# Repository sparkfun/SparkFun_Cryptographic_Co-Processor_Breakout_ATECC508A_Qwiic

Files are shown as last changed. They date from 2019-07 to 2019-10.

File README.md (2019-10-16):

SparkFun Cryptographic Co-Processor Breakout - ATECC508A (Qwiic)
========================================

SparkFun Cryptographic Breakout

[*SparkFun Cryptographic Co-Processor Breakout - ATECC508A (Qwiic) (DEV-15573)*](https://www.sparkfun.com/products/15573)

The SparkFun Cryptographic Co-processor Breakout ATECC508A (Qwiic) takes all the great features of the Microchip ATECC508A cryptographic authentication device and adds two Qwiic ports for plug and play functionality. The ATECC508A chip is capable of many cryptographic processes, including, but not limited to:

* An asymmetric key/signature solution based upon Elliptic Curve Cryptography.
* A standard hash-based challenge-response protocol using a SHA-256 algorithm.
* A FIPS random number generator. 

Embedded in the chip is a 10 Kb EEPROM array that can be used for storing keys, certificates, data, consumption logging, and security configurations. Access to the sections of memory can then be restricted and the configuration locked to prevent changes.

Each ATECC508A ships with a guaranteed unique 72-bit serial number and includes several security features to prevent physical attacks on the device itself, or logical attacks on the data transmitted between the device.

**&#x1F512; Note:** This board is **NOT** capable of encrypting and decrypting data. It can however, perform quite a few cryptographic authentication processes such as secure private key creation, secure key storage, and digital signature creation and verification.

Repository Contents
-------------------

* **/Documentation** - Data sheets, additional product information
* **/Enclosure** - Enclosure files 
* **/Firmware** - Example code 
* **/Hardware** - Eagle design files (.brd, .sch)
* **/Libraries** - Libraries for use with the <PRODUCT NAME>
* **/Production** - Production panel files (.brd)
* **/Software** - Related software for the <PRODUCT NAME>

Documentation
--------------
* **[SparkFun ATECCX08A Arduino Library](https://github.com/sparkfun/SparkFun_ATECCX08a_Arduino_Library)** - Arduino library for the ATECCX08A.
* **[SparkFun Cryptographic Breakout Hookup Guide](https://learn.sparkfun.com/tutorials/cryptographic-co-processor-atecc508a-qwiic-hookup-guide)** - Basic hookup guide for the SparkFun Cryptographic Co-Processor Breakout.

Product Versions
----------------
* [DEV-15573](https://www.sparkfun.com/products/15573)- Initial Release

License Information
-------------------

This product is _**open source**_! 

Please review the LICENSE.md file for license information. 

If you have any questions or concerns on licensing, please contact technical support through the [SparkFun forum](https://forum.sparkfun.com/index.php).

Please use, reuse, and modify these files as you see fit. Please maintain attribution to SparkFun Electronics and release any derivative under the same license.

Distributed as-is; no warranty is given.

- Your friends at SparkFun.

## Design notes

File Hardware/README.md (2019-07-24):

SparkFun <PRODUCT NAME> Design Files
=====================================

The .sch and .brd files hare are Eagle CAD schematic and PCB design files from SparkFun Electronics.
A freeware version of Eagle can be found [here](http://www.cadsoftusa.com/download-eagle/freeware/).

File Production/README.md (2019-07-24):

SparkFun <PRODUCT NAME> Production Files
=========================================

These are the production files SparkFun uses for printing PCBs.

License Information
-------------------
This product is open source! 

The hardware is released under [Creative Commons ShareAlike 4.0 International](https://creativecommons.org/licenses/by-sa/4.0/).

Please use, reuse, and modify these files as you see fit. Please maintain attribution to SparkFun Electronics and release anything derivative under the same license.

Distributed as-is; no warranty is given.

- Your friends at SparkFun.

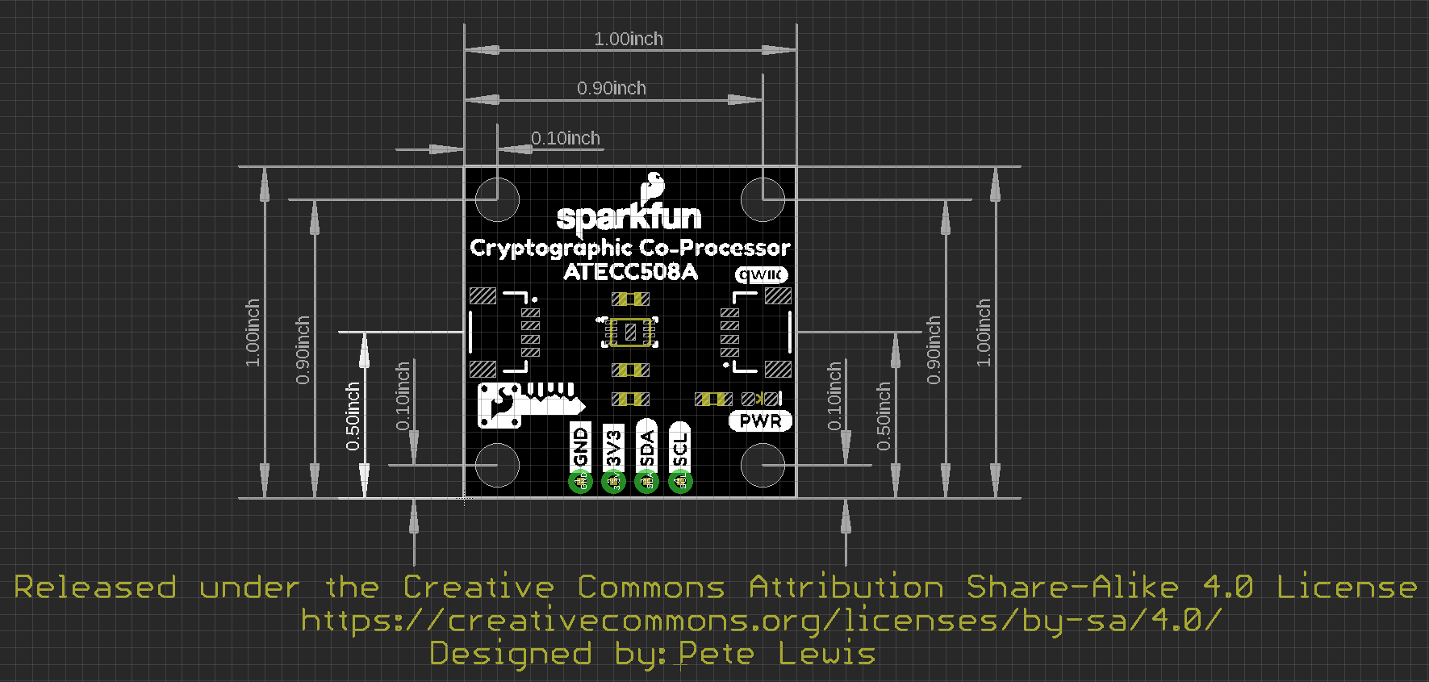
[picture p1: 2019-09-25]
Documentation/SparkFun_Cryptographic_Co-processor_ATECC508A_Dimensions.png

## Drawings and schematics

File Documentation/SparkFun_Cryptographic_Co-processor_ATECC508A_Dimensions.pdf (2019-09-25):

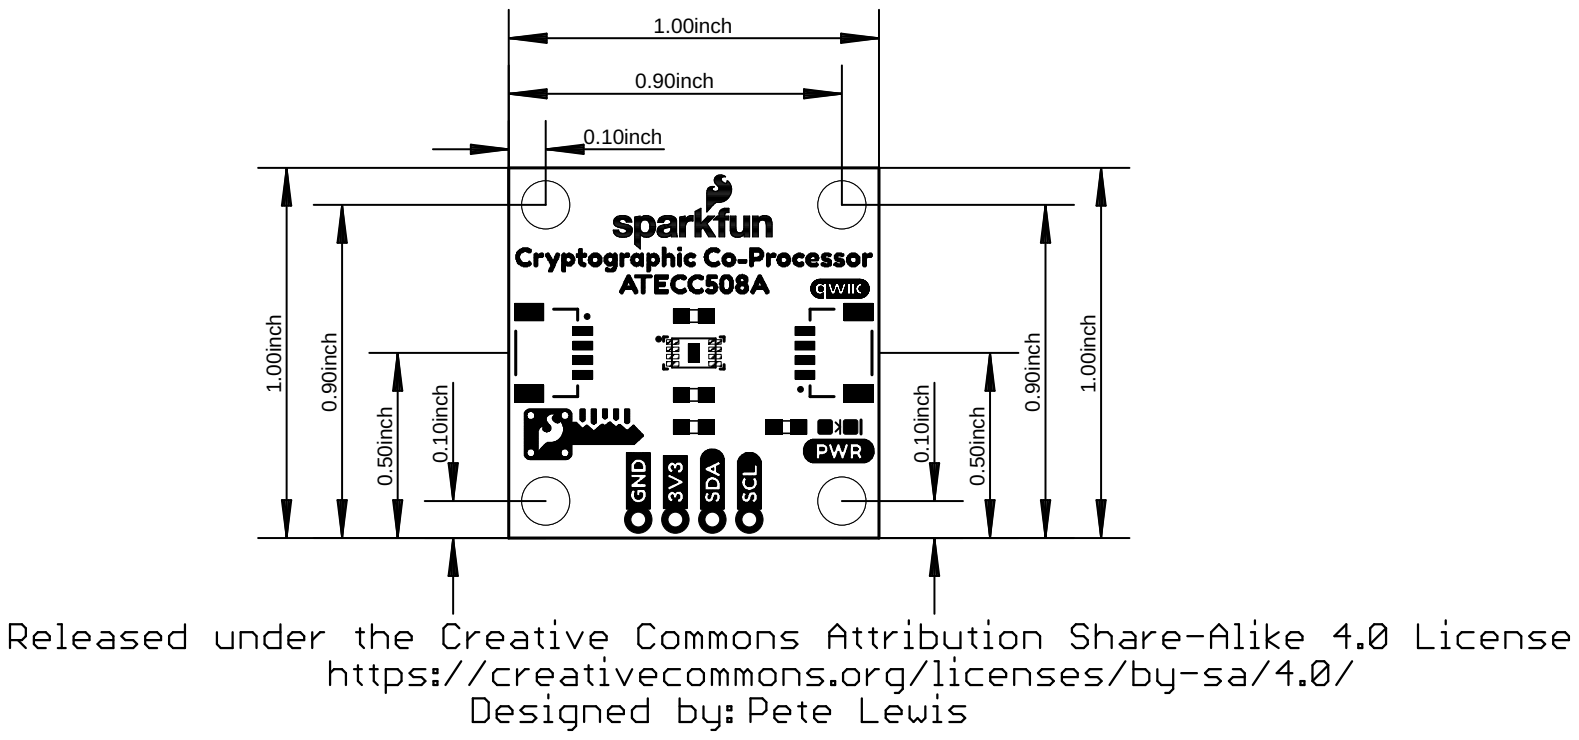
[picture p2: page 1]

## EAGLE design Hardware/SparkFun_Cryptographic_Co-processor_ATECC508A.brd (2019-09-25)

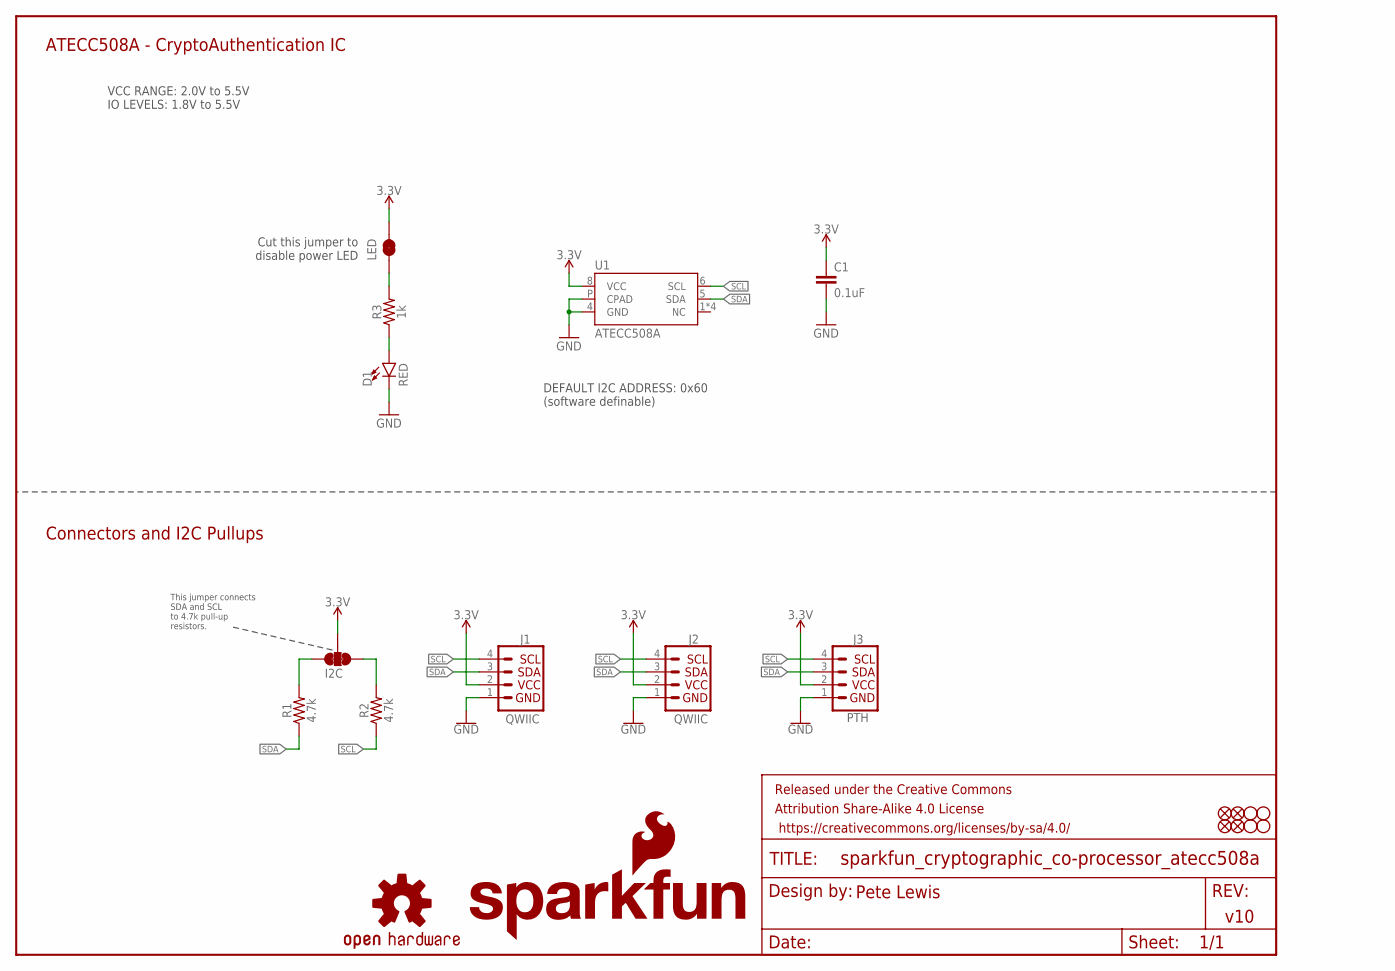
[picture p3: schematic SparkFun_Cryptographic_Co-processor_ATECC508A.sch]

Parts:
C1: 0.1uF; 0603
D1: RED; LED-0603
FD1, FD2, FD3, FD4: FIDUCIAL1X2; FIDUCIAL-1X2
FRAME1: FRAME-LETTER; CREATIVE_COMMONS
H1, H2, H3, H4: STAND-OFF
I2C: JUMPER-SMT_3_2-NC_TRACE_SILK; SMT-JUMPER_3_2-NC_TRACE_SILK
J1, J2: QWIIC; JST04_1MM_RA
J3: PTH; 1X04_NO_SILK
LED: JUMPER-SMT_2_NC_TRACE_SILK; SMT-JUMPER_2_NC_TRACE_SILK
LOGO1: SFE_LOGO_NAME_FLAME.1_INCH; SFE_LOGO_NAME_FLAME_.1
LOGO4: OSHW-LOGOS; OSHW-LOGO-S
R1, R2: 4.7k; 0603
R3: 1k; 0603
U1: ATECC508A; UDFN_2X3MM

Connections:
3.3V: C1.1, I2C.2, J1.2, J2.2, J3.2, LED.2, U1.8 (VCC)
GND: C1.2, D1.C, J1.1, J2.1, J3.1, U1.4 (GND), U1.P (CPAD)
unnamed: D1.A, R3.1
unnamed: I2C.3, R1.2
unnamed: I2C.1, R2.2
unnamed: LED.1, R3.2
SCL: J1.4, J2.4, J3.4, R2.1, U1.6 (SCL)
SDA: J1.3, J2.3, J3.3, R1.1, U1.5 (SDA)

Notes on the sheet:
This jumper connects SDA and SCL to 4.7k pull-up resistors.
v10
Pete Lewis
ATECC508A - CryptoAuthentication IC
VCC RANGE: 2.0V to 5.5V IO LEVELS: 1.8V to 5.5V
Connectors and I2C Pullups
Cut this jumper to disable power LED
DEFAULT I2C ADDRESS: 0x60 (software definable)

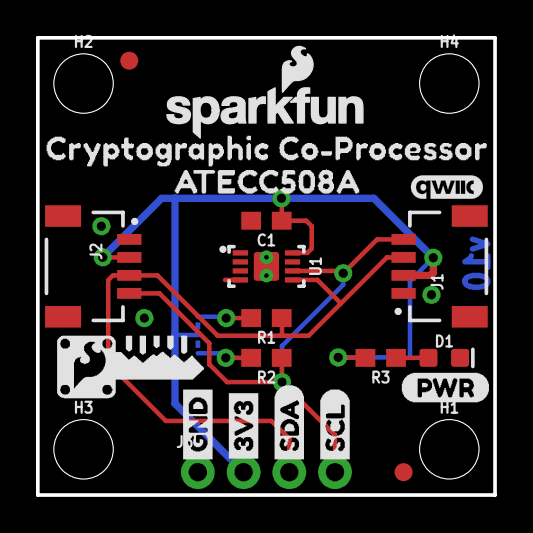
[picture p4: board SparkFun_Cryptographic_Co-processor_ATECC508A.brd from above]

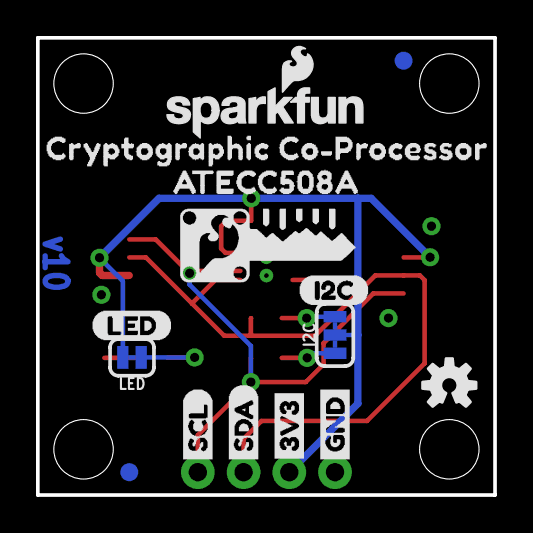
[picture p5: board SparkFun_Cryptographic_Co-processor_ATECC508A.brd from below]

Board: 2 copper layers, 25.4 x 25.4 mm, 41 parts (15 on the bottom side), 8 nets.

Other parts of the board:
LOGO2: SFE_LOGO_NAME_FLAME.1_INCH; SFE_LOGO_NAME_FLAME_.1
U$1: LED0
U$2, U$7: 3V34
U$3, U$5: SDA5
U$4, U$8: GND3
U$6, U$10: SCL6
U$11, U$17: CRYPTOGRAPHIC_CO#PROCESSOR0
U$12, U$14: ATECC508A0
U$13: PWR0
U$15, U$18: CRYPTO_COPROCESSOR_LOGO#04#PNG
U$16: QWIIC_4MM
U$22: I2C0

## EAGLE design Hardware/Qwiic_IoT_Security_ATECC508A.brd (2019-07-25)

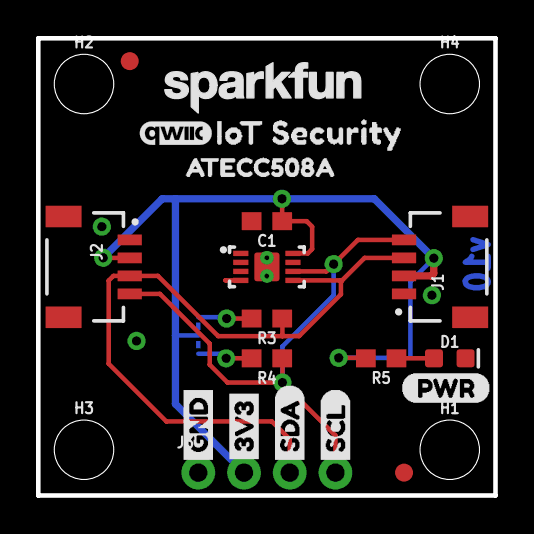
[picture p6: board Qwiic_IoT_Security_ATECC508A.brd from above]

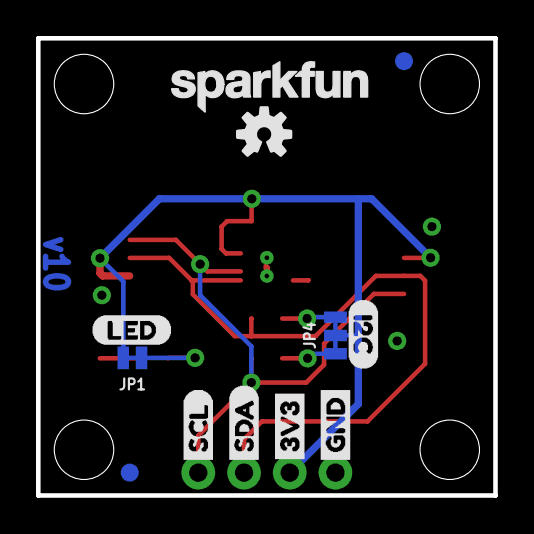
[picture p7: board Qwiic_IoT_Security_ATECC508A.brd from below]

Board: 2 copper layers, 25.4 x 25.4 mm, 37 parts (12 on the bottom side), 8 nets.

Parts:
C1: 0.1uF; 0603
D1: RED; LED-0603
FD1, FD2, FD3, FD4: FIDUCIAL1X2; FIDUCIAL-1X2
FRAME1: FRAME-LETTER; CREATIVE_COMMONS
H1, H2, H3, H4: STAND-OFF
J1, J2: QWIIC; JST04_1MM_RA
J3: PTH; 1X04_NO_SILK
JP1: SMT-JUMPER_2_NC_TRACE_NO-SILK
JP4: SMT-JUMPER_3_2-NC_TRACE_NO-SILK
LOGO1: SFE_LOGO_NAME.1_INCH; SFE_LOGO_NAME_.1
LOGO3: SFE_LOGO_NAME.1_INCH; SFE_LOGO_NAME_.1@1
LOGO4: OSHW-LOGOS; OSHW-LOGO-S
R3, R4: 4.7k; 0603
R5: 1k; 0603
U1: ATECC508A; UDFN_2X3MM
U$1: LED0
U$2, U$7: 3V34
U$3, U$5: SDA5
U$4, U$8: GND3
U$6, U$10: SCL6
U$12: ATECC508A0
U$13: PWR0
U$15: IOT_SECURITY0
U$16: QWIIC_4MM
U$22: I2C0

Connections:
3.3V: C1.1, J1.2, J2.2, J3.2, JP1.2, JP4.2, U1.8
GND: C1.2, D1.C, J1.1, J2.1, J3.1, U1.4, U1.P
unnamed: D1.A, R5.1
unnamed: JP4.3, R3.2
unnamed: JP4.1, R4.2
unnamed: JP1.1, R5.2
SCL: J1.4, J2.4, J3.4, R4.1, U1.6
SDA: J1.3, J2.3, J3.3, R3.1, U1.5

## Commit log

2019-07-24 eagle local library, device/symbol/footprint created, added datasheet
2019-07-25 v10 hardware layed out (first attempt)
    [Qwiic_IoT_Security_ATECC508A.brd, Qwiic_IoT_Security_ATECC508A.sch]
2019-07-25 rotated LED jumper bPlace label so it reads upright
    [Qwiic_IoT_Security_ATECC508A.brd]
2019-07-26 rename and adjusted silk for protos
    version to v01
    added silk to bplace with name
    [SparkFun_Qwiic_Encryption_ATECC508A.brd, SparkFun_Qwiic_Encryption_ATECC508A.sch]
2019-09-12 Changed silk to correct product name
    Also updated sch and board to "v10".
    [SparkFun_Qwiic_Encryption_ATECC508A.brd, SparkFun_Qwiic_Encryption_ATECC508A.sch]
2019-09-12 Changed eagle file names to match product name
    [SparkFun_Cryptographic_Co-processor_ATECC508A.brd, SparkFun_Cryptographic_Co-processor_ATECC508A.sch]
2019-09-13 silk on jumpers, rotate I2C jumper label, changed name on symbols to match
    [SparkFun_Cryptographic_Co-processor_ATECC508A.brd, SparkFun_Cryptographic_Co-processor_ATECC508A.sch]
2019-09-13 Design review changes - silk, sch, prod id - ready for reds
    -added sweet key graphic
    -added default I2C address to sch
    -added PROD ID to part in library. (note, still need to migrate to official libraries when this goes live).
    -added NC pin to symbol/dev for IC.
    -nudges a via and some traces to line up with key graphic hole
    -rotated LED label to match others' orientation.
    -swapped jumper packages to include silk outlines
    [SparkFun_Cryptographic_Co-processor_ATECC508A.brd, SparkFun_Cryptographic_Co-processor_ATECC508A.sch]
2019-09-13 prod id for IC
    [SparkFun_Cryptographic_Co-processor_ATECC508A.brd, SparkFun_Cryptographic_Co-processor_ATECC508A.sch]
2019-09-13 swapped over to official SFE library for IC
    added name and value to footprint.
    removed local mini library.
    [SparkFun_Cryptographic_Co-processor_ATECC508A.brd, SparkFun_Cryptographic_Co-processor_ATECC508A.sch]
2019-09-16 GND wire stub removal - GND pad off of IC and center pad GND nubs
    [SparkFun_Cryptographic_Co-processor_ATECC508A.brd]
2019-09-16 one last GND stub
    note, this is note being caught in my DRC with Eagle 9.4.2, so not sure what's going on here.
    [SparkFun_Cryptographic_Co-processor_ATECC508A.brd]
2019-09-25 Augmented dimensions in BRD and included PNG and PDF for reference
    [SparkFun_Cryptographic_Co-processor_ATECC508A.brd]

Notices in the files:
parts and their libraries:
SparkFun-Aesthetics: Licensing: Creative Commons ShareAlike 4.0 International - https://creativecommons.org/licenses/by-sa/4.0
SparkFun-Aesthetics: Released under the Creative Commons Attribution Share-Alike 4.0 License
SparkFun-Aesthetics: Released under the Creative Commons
